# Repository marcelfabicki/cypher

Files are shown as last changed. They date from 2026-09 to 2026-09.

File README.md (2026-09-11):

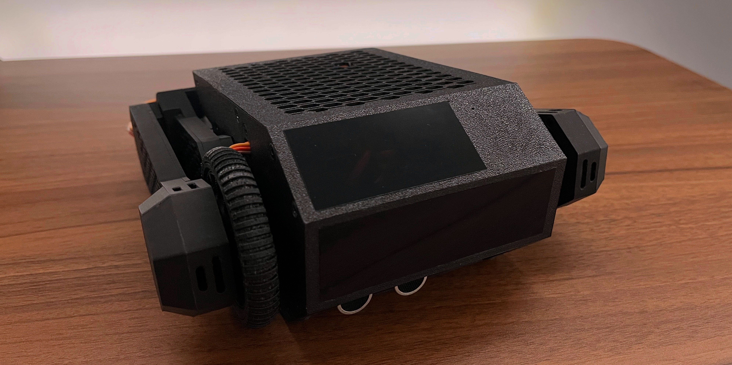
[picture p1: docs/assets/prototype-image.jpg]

<p align="center"><sub><i>Assembled Prototype v0.1.0</i></sub></p>

<h1 style="text-align:center;">CYPHER</h1>

**CYPHER** is an open-source, autonomous two-wheeled bipedal AI robot. Being a wheeled-legged robot, powered by a Raspberry Pi 5 and equipped with a camera and distance sensor, Cypher can navigate around obstacles and maintain balance on uneven surfaces, but most notably, through OpenAI's Realtime API and inspired by the personality of Tars (Interstellar), Cypher can talk, ask questions, and act on commands (with its own unique personality and humour).

## Project Status & Next Steps

The robot has been fully designed, printed and assembled. All hardware required for self-balancing and movement including servos, wheel BLDC motors and encoders, buck converters, and ultrasonic distance sensor have been installed and connected to the PCB so the next stage is to begin coding leg-movement and self-balancing firmware on the ESP32.

Some modifications had to be made to the PCB. These included soldering wires to the underside corresponding to pins 5, 15, 21, and 22 of the ESP32 to allow for I2C communication with the AS5600 magnetic encoders - originally PCB routed to PWM input pins which unfortunately proved unreliable. In addition 2.2k pull-up resisters were soldered to pins 5 and 15 to stabilise the I2C line. In v1 the PCB files ([hardware/pcb/](hardware/pcb/)) will be re-routed according to any modification.

The current design (available inside [hardware/cad](hardware/cad/)) includes approximately 45 3d-printed parts and over 130 screws to assemble. The BOM, full assembly instructions and documentation will be available with v1. 

## Hardware Overview
- **Battery:** 11.1V 3S 2200mAh LiPo
- **PCB:** 2 layer custom PCB for power distribution & signal routing
- **Compute:** ESP32 + Raspberry Pi 5
- **Sensors:** AS5600 magnetic encoders, INA226 voltage sensor, MPU6050 IMU, INMP441 microphone, HCSR04 ultrasonic distance sensor
- **BLDC Driver:** SimpleFOCMini driver
- **Actuators:** MG996R + 20kg servos, 2208 80T brushless gimbal motors
- **Buck-Converters:** XL4016, 60W DFRobot Adjustable Buck Module

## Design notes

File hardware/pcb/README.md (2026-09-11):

# PCB Hardware Status

## Rev 0.1 (Current - Requires Modification)
- Functional with manual modifications (soldering additional wires and pull-up resistors to the underside ESP32 pins)
- Gerbers will be included once changes for Rev 0.2 have been made

## Planned for Rev 0.2
- Re-route AS5600 magnetic encoder connector traces with ESP32
- Add 2.2k I2C pull-ups

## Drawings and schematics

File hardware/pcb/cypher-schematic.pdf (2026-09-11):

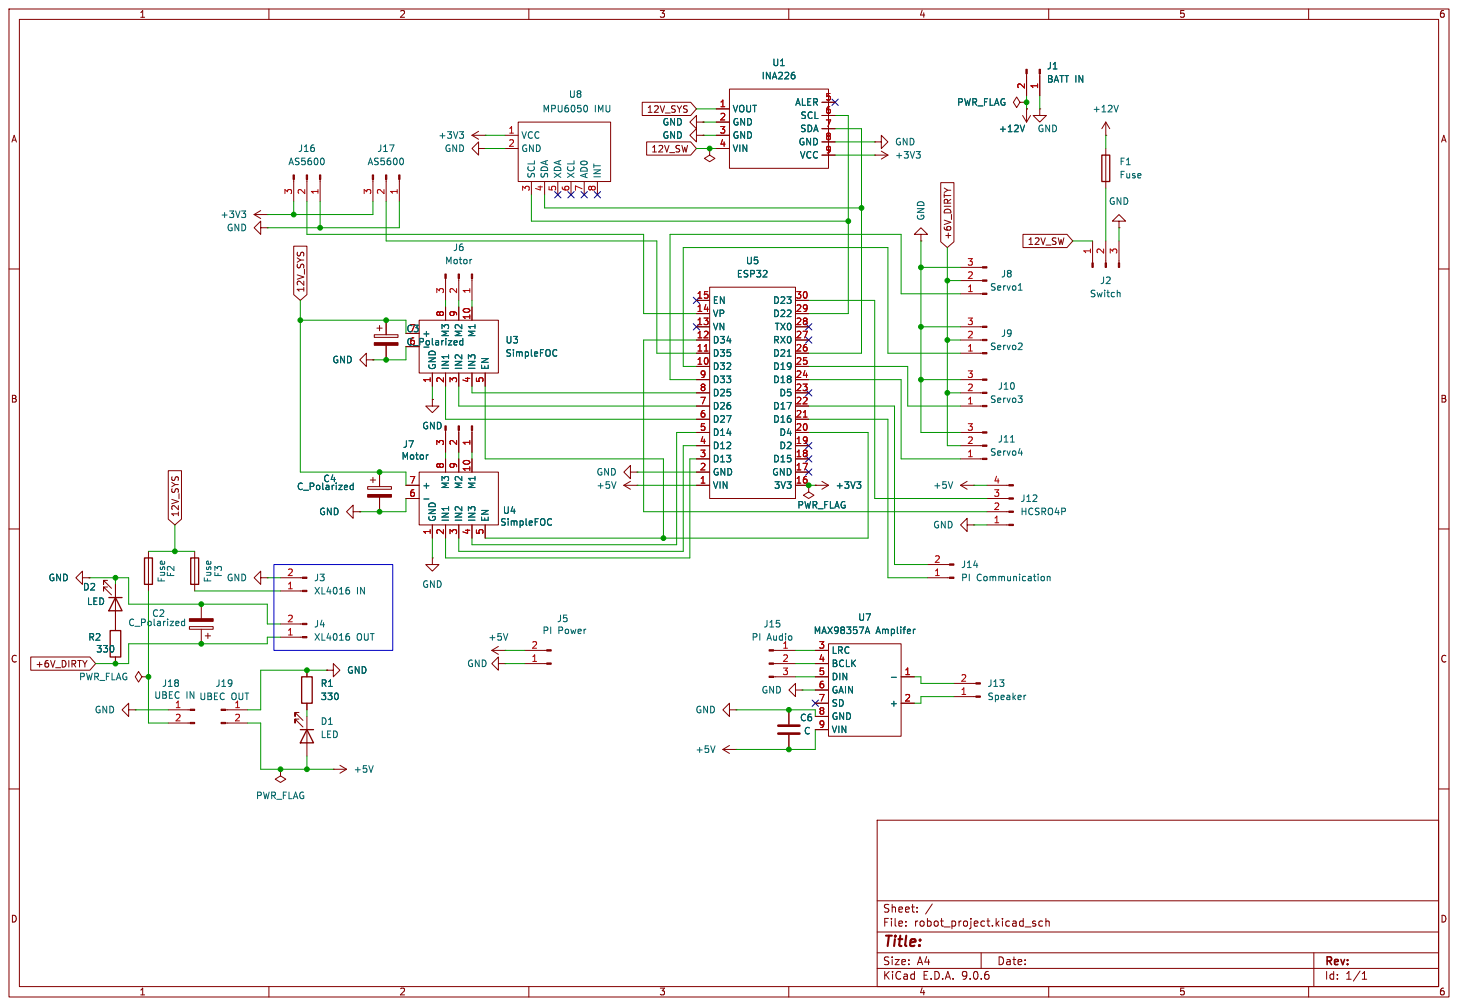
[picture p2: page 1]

Id: 1/1 Title: File: robot_project.kicad_sch Sheet: /

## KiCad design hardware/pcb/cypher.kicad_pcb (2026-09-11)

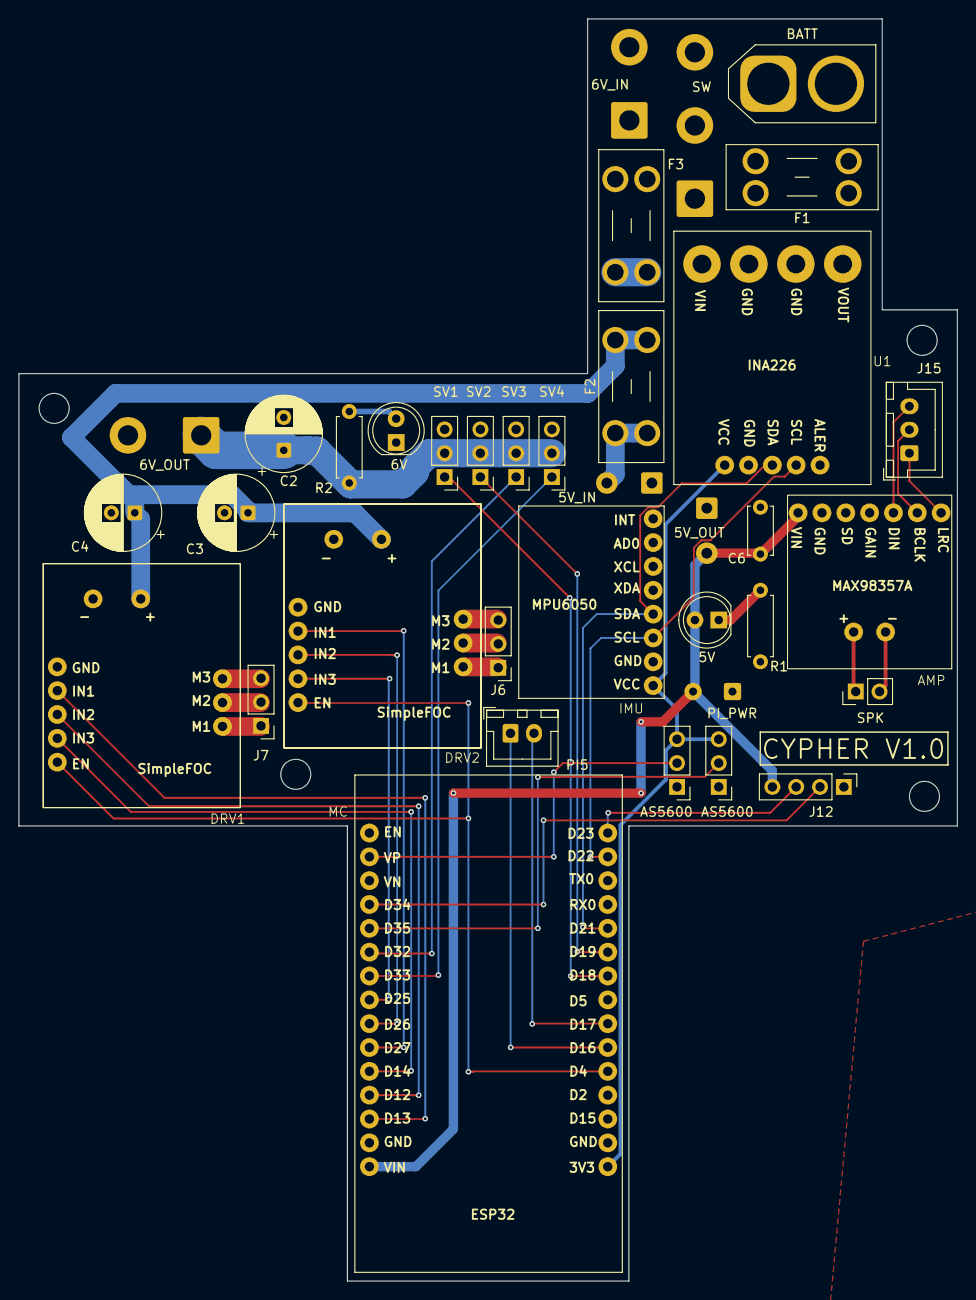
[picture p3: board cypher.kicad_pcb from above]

Board: 2 copper layers, 100.0 x 134.5 mm, 36 parts (0 on the bottom side), 42 nets.

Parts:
5V, 6V: LED; LED_D5.0mm
5V_IN: UBEC IN; SolderWire-0.5sqmm_1x02_P4.8mm_D0.9mm_OD2.3mm
5V_OUT: UBEC OUT; SolderWire-0.5sqmm_1x02_P4.8mm_D0.9mm_OD2.3mm
6V_IN: XL4016 IN; SolderWire-1.5sqmm_1x02_P7.8mm_D1.7mm_OD3.9mm
6V_OUT: XL4016 OUT; SolderWire-1.5sqmm_1x02_P7.8mm_D1.7mm_OD3.9mm
AMP: MAX98357A Amplifer; MAX98357A Module
AS5600, AS5600#2: AS5600; PinHeader_1x03_P2.54mm_Vertical
BATT: BATT IN; AMASS_XT60-F_1x02_P7.20mm_Vertical
C2: C_Polarized; CP_Radial_D8.0mm_P3.50mm
C3, C4: C_Polarized; CP_Radial_D8.0mm_P2.50mm
C6: C; C_Disc_D5.0mm_W2.5mm_P5.00mm
DRV1, DRV2: SimpleFOC
F1, F2, F3: Fuse; Fuseholder_Blade_Mini_Keystone_3568
IMU: MPU6050 IMU; MPU6050 Module
J6, J7: Motor; PinHeader_1x03_P2.54mm_Vertical
J12: HCSRO4P; PinHeader_1x04_P2.54mm_Vertical
J15: PI Audio; JST_XH_B3B-XH-A_1x03_P2.50mm_Vertical
MC: ESP32; ESP32 Module
PI5: PI Communication; JST_XH_B2B-XH-A_1x02_P2.50mm_Vertical
PI_PWR: PI Power; SolderWire-0.25sqmm_1x02_P4.2mm_D0.65mm_OD1.7mm
R1, R2: 330; R_Axial_DIN0207_L6.3mm_D2.5mm_P7.62mm_Horizontal
SPK: Speaker; PinHeader_1x02_P2.54mm_Vertical
SV1: Servo4; PinHeader_1x03_P2.54mm_Vertical
SV2: Servo3; PinHeader_1x03_P2.54mm_Vertical
SV3: Servo2; PinHeader_1x03_P2.54mm_Vertical
SV4: Servo1; PinHeader_1x03_P2.54mm_Vertical
SW: Switch; SolderWire-1.5sqmm_1x03_P7.8mm_D1.7mm_OD3.9mm
U1: INA226; INA226 Module

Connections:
12V_SW: SW.1, U1.4 (VIN)
12V_SYS: C3.1, C4.1, DRV1.7 (+), DRV2.7 (+), F2.2, F3.1, U1.1 (VOUT)
+3V3: AS5600.3, AS5600#2.3, IMU.1 (VCC), MC.16 (3V3), U1.9 (VCC)
+5V: 5V.2 (A), 5V_OUT.2, AMP.9 (VIN), C6.2, J12.4, MC.1 (VIN), PI_PWR.2
+6V_DIRTY: 6V_OUT.1, C2.1, R2.1, SV1.2, SV2.2, SV3.2, SV4.2
+12V: BATT.2, F1.1
GND: 5V_IN.1, 5V_OUT.1, 6V.1 (K), 6V_IN.2, 6V_OUT.2, AMP.6 (GAIN), AMP.8 (GND), AS5600.1, AS5600#2.1, BATT.1, C2.2, C3.2, C4.2, C6.1, DRV1.1 (GND), DRV1.6 (-), DRV2.1 (GND), DRV2.6 (-), IMU.2 (GND), J12.1, MC.2 (GND), PI_PWR.1, R1.2, SV1.3, SV2.3, SV3.3, SV4.3, SW.3, U1.2 (GND), U1.3 (GND), U1.8 (GND)
unnamed: 5V.1 (K), R1.1
unnamed: 6V.2 (A), R2.2
unnamed: F1.2, SW.2
unnamed: 6V_IN.1, F3.2
unnamed: DRV2.10 (M1), J6.1
unnamed: DRV2.9 (M2), J6.2
unnamed: DRV2.8 (M3), J6.3
unnamed: DRV1.10 (M1), J7.1
unnamed: DRV1.9 (M2), J7.2
unnamed: DRV1.8 (M3), J7.3
unnamed: MC.9 (D33), SV4.1
unnamed: MC.10 (D32), SV3.1
unnamed: MC.25 (D19), SV2.1
unnamed: MC.24 (D18), SV1.1
unnamed: J12.2, MC.12 (D34)
unnamed: J12.3, MC.30 (D23)
unnamed: AMP.2 (+), SPK.1
unnamed: AMP.1 (-), SPK.2
unnamed: MC.21 (D16), PI5.1
unnamed: MC.22 (D17), PI5.2
unnamed: AMP.3 (LRC), J15.1
unnamed: AMP.4 (BCLK), J15.2
unnamed: AMP.5 (DIN), J15.3
unnamed: AS5600#2.2, MC.14 (VP)
unnamed: AS5600.2, MC.11 (D35)
unnamed: 5V_IN.2, F2.1
unnamed: IMU.3 (SCL), MC.29 (D22), U1.6 (SCL)
unnamed: IMU.4 (SDA), MC.26 (D21), U1.7 (SDA)
unnamed: DRV1.5 (EN), DRV2.5 (EN), MC.20 (D4)
unnamed: DRV2.2 (IN1), MC.6 (D27)
unnamed: DRV2.3 (IN2), MC.7 (D26)
unnamed: DRV2.4 (IN3), MC.8 (D25)
unnamed: DRV1.2 (IN1), MC.3 (D13)
unnamed: DRV1.3 (IN2), MC.4 (D12)
unnamed: DRV1.4 (IN3), MC.5 (D14)

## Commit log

2026-09-11 add initial cad model v0.1.0
2026-09-11 add rev 0.1 pcb schematic and board layout files
    [cypher.kicad_pcb, cypher.kicad_sch]
2026-09-17 partial servo testing code
2026-11-11 add servo selection and angle input
2026-11-11 add servo write function
2026-11-13 add servo error
2026-11-13 begin inverse kinematics servo test file
